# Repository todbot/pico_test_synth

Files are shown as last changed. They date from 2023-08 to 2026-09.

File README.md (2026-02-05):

# pico_test_synth

A simple 
[Raspberry Pi Pico RP2040 or Pico 2 RP2350](https://www.raspberrypi.com/documentation/microcontrollers/raspberry-pi-pico.html)-based
synth to experiment with [`synthio`](https://github.com/todbot/circuitpython-synthio-tricks) and [Mozzi](https://github.com/sensorium/Mozzi).



### pico_test_synth2
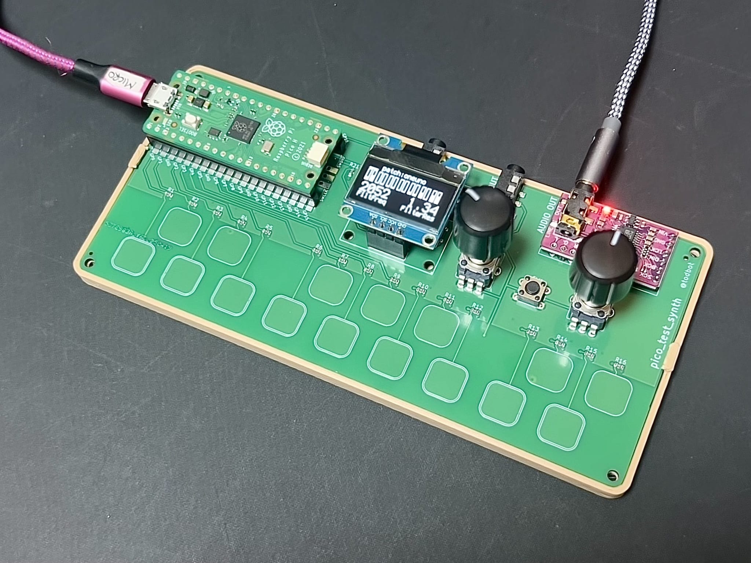
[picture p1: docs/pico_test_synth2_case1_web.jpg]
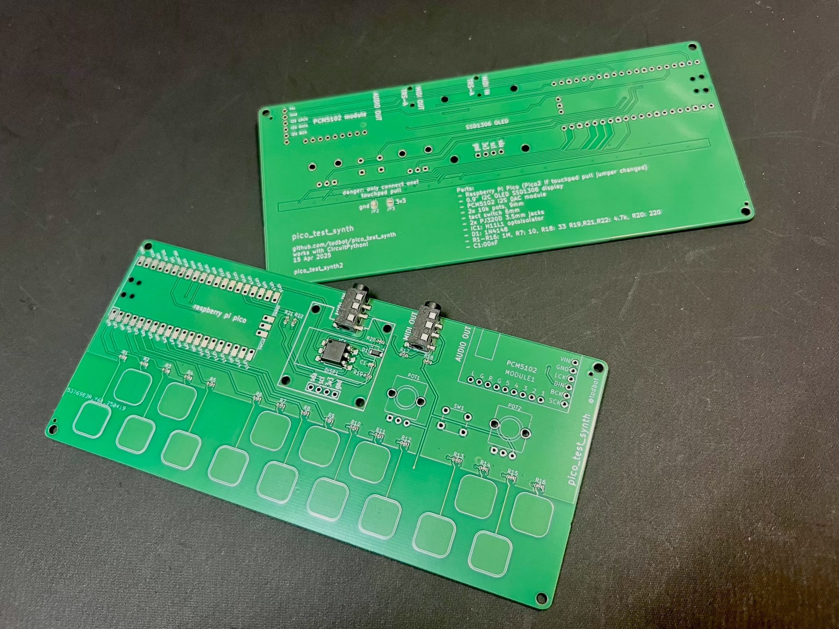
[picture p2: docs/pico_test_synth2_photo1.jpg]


### pico_test_synth, the original
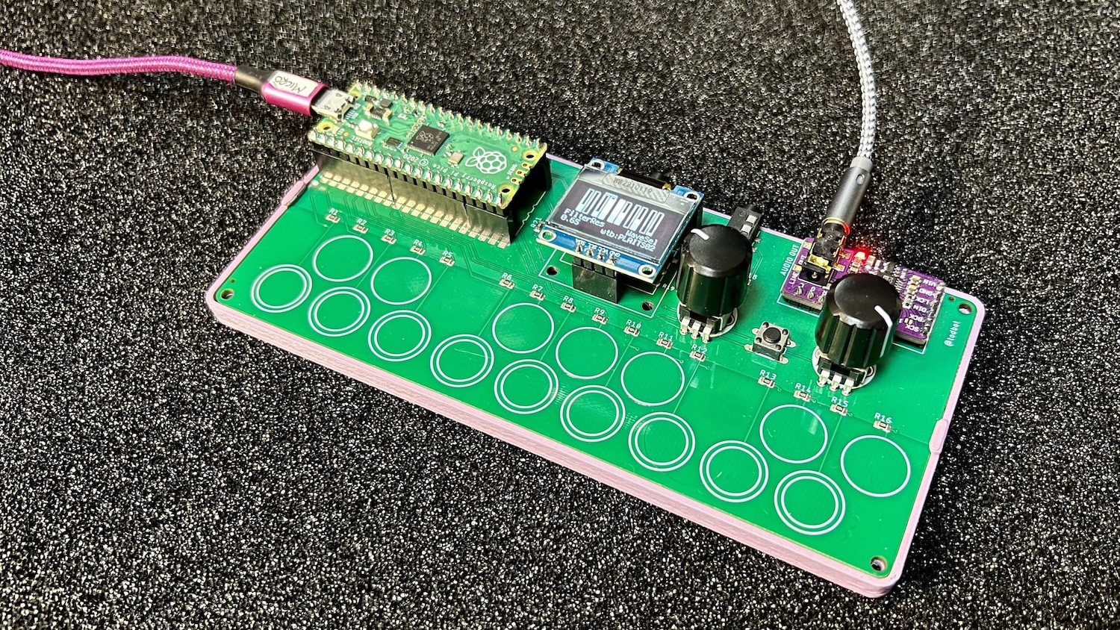
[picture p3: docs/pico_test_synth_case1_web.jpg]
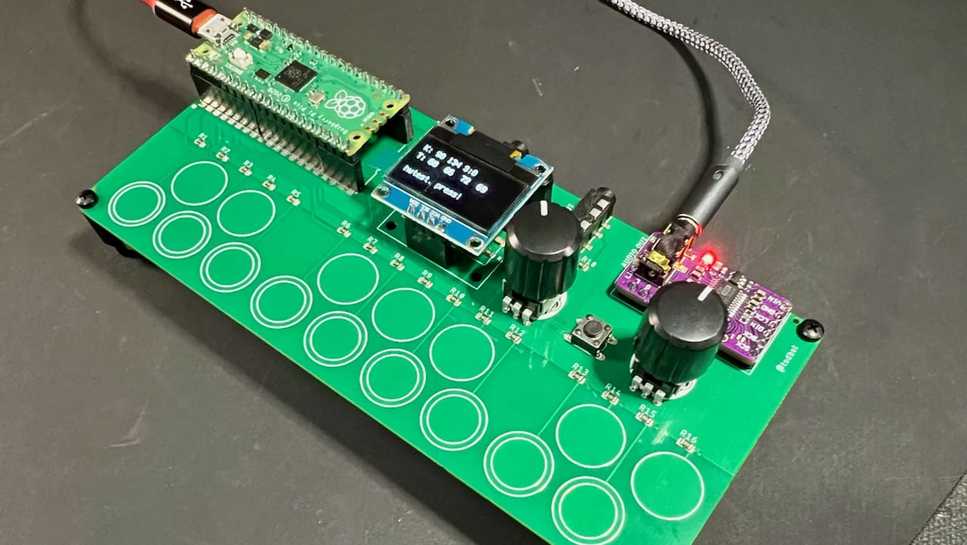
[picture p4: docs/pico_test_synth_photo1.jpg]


<h3>video demo</h3>

video demo (https://www.youtube.com/watch?v=9U2Dn7ckdbs)

** **[Available on Tindie](https://www.tindie.com/products/todbot/pico_test_synth/)** **

### Features

* [PCM5102 I2S DAC](https://todbot.com/blog/2023/05/16/cheap-stereo-line-out-i2s-dac-for-circuitpython-arduino-synths/) footprint for high-quality stereo audio out
* Optoisolated MIDI Input via [MIDI TRS-A 3.5mm jack](https://www.perfectcircuit.com/make-noise-0-coast-midi-cable.html)
* MIDI output via MIDI TRS-A 3.5mm jack
* Two pots for controlling parameters
* One switch for controlling parameters
* 16 capsense touch buttons for synth triggering
* USB MIDI in/out of course too
* **(NOTE: the pico_test_synth1 PCB will NOT work with the Pico2, since its RP2350 chip has a hardware error)**

#### pico_test_synth2 vs pico_test_synth

- Both use the same components
- Both run the same code 
- Both fit in the same enclosure
- `pico_test_synth2` drawn in Kicad; `pico_test_synth` drawn in Eagle
- `pico_test_synth2` has square buttons; `pico_test_synth` has round buttons
- `pico_test_synth2` can work with Pico 2 and Pico 
- `pico_test_synth` can only work with Pico1

### Software

Programs written for [`qtpy_synth`](https://github.com/todbot/qtpy_synth/)
will work with this board too with minimal changes.

Some programs written specifically for this board:

* [TBish](https://github.com/todbot/pico_test_synth/tree/main/circuitpython/tbish/) - a TB303-like synth demo ([video demo](https://www.youtube.com/watch?v=1AflpXbEIno))
* [monosynth1](https://github.com/todbot/pico_test_synth/tree/main/arduino/monosynth1) - a full Moog-like monosynth written in Arduino & Mozzi 
* [hwtest](https://github.com/todbot/pico_test_synth/tree/main/circuitpython/hwtest/code.py) - test out the hardware with a simple synth ([video demo](https://www.youtube.com/watch?v=9U2Dn7ckdbs))
* [wavesynth](https://github.com/todbot/pico_test_synth/tree/main/circuitpython/wavesynth/) - port of wavesynth for qtpy_synth board with some improvements

#### See also:
- [CircuitPython Synthio Tricks](https://github.com/todbot/circuitpython-synthio-tricks)
  - Contains [many other synthio examples](https://github.com/todbot/circuitpython-synthio-tricks/tree/main/examples) that can work with this synth with minimal changes
- [Synthio Tutorial](https://todbot.github.io/CircuitPython_Synthio_Tutorial/) 
  - a getting-started guide for `synthio` ending with some full synthesiser voices 

### Enclosure

As seen in the photos, there is a simple [3d-printable enclosure available on Printables](https://www.printables.com/model/784414-case-for-pico_test_synth-circuitpython-synthesizer). 
It's fast to print and you can snap the PCB in to quickly get started,
or use M2.5 screws and nuts to secure the PCB more permanently.

### Pins used

The board uses all of the Raspberry Pi Pico pins:

* `board.GP28` - middle button
* `board.GP27` - right knob
* `board.GP26` - left knob
* `board.GP22` - I2S data
* `board.GP21` - I2S LR  clock
* `board.GP20` - I2S bit clock
* `board.GP19` - I2C SCL for OLED display
* `board.GP18` - I2C SDA for OLED display
* `board.GP17` - TRS UART MIDI in
* `board.GP16` - TRS UART MIDI out
* `board.GP15`..`board.GP0` -- touch pads 1-16

For more details see [`hwtest/code.py`](https://github.com/todbot/pico_test_synth/tree/main/circuitpython/hwtest/code.py).

### Schematics

#### pico_test_synth2 ####
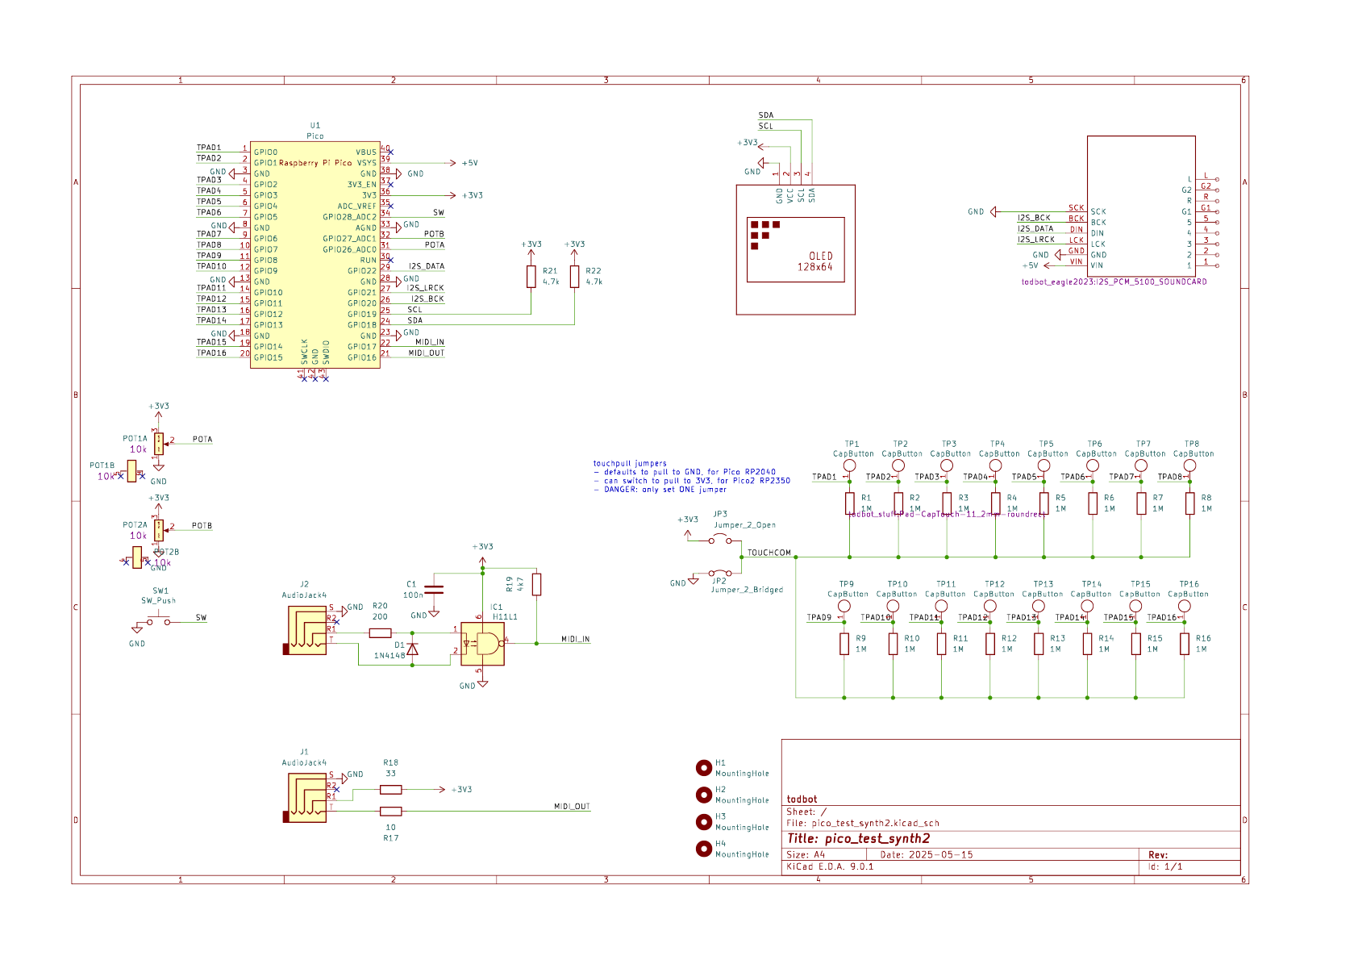
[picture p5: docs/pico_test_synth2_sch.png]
[](./schematics/pico_test_synth2/pico_test_synth2_sch.pdf)

#### pico_test_synth, original ####
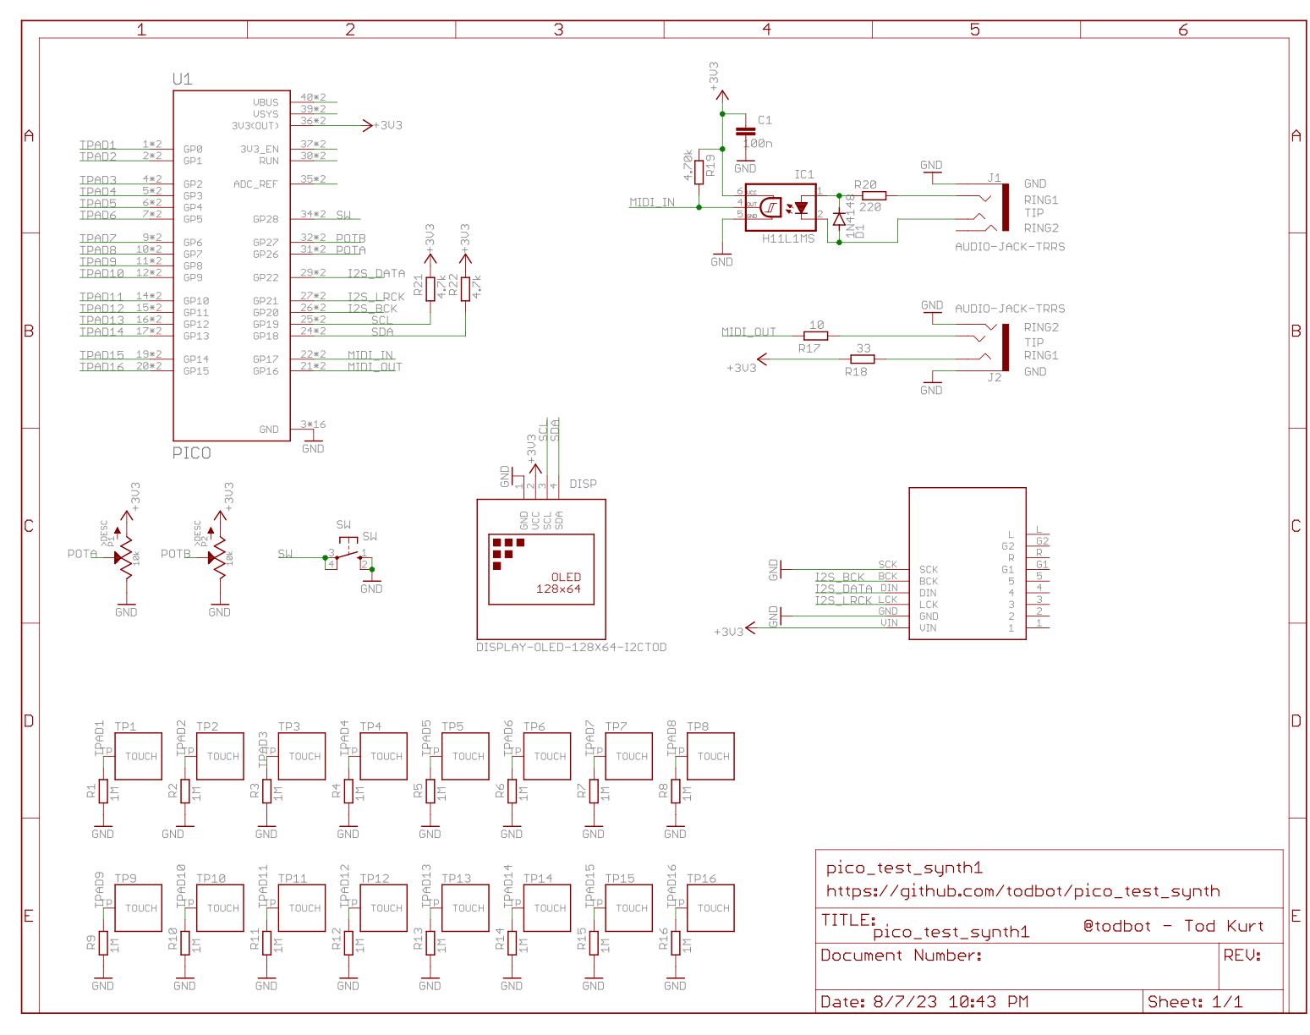
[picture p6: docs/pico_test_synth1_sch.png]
[](./schematics/pico_test_synth1/pico_test_synth1_sch.pdf)

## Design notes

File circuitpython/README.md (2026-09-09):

# CircuitPython apps for pico_test_synth

CircuitPython demos for the pico_test_synth and pico_test_synth2 boards.

* [`hwtest`](hwtest/) - canonical hardware/pin reference for this board and a simple synth. Start here. 
* [`synthtools_polysynth`](synthtools_polysynth/) - 16-pad chromatic polysynth based on `SubtractiveSynth`, 18 parameters grouped into 6 named sections, two pots per pair
* [`synthtools_swarm`](synthtools_swarm/) - `SwarmSynth` drone — up to 8 detuned oscillators per note 
* [`synthtools_arp`](synthtools_arp/) - hold pads, `Arpeggiator` plays them back 
* [`wavesynth`](wavesynth/) - wavetable polysynth with 9 saveable patches 
* [`tbish`](tbish/) - TB-303-like monosynth with step-sequencer
* [`tbish2`](tbish2/) - TB-303-style acid bassline on `BasslineSynth`, with a step sequencer. Will try to use `audiofilters`/`audiodelays` for fatter sound
* [`synth1`](synth1/) - small demo synth: filter sweeps, detune, MIDI in 

## Install

You can use circup to install needed libraries:
```
circup install -r requirements.txt
```

For each demo, copy the contents of the directory flat onto the CIRCUITPY
root and reset.

## Notes

### Sample rate

These demos run at 22050 Hz sample rate in stereo, this works on RP2040 (Pico)
and RP2350 (Pico2). The Pico2 can do 44100 Hz sample rate. 

Every demo sets `FILT_F_MAX` on its synth subclass before constructing it to
be below the Nyquist frequency for the sample rate (e.g. 11 kHz for 22050 Hz),
since filter frequency above Nyquist is undefined.

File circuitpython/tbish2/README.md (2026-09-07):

# TBish2 synth

A TB-303 inspired monophonic bass synth: [`tbish/`](../tbish/) rebuilt on
[`synthtools`](https://github.com/todbot/CircuitPython_SynthTools)'
`BasslineSynth`.

Video demo of the original: https://www.youtube.com/watch?v=1AflpXbEIno

## Why this exists

`BasslineSynth` is a direct port of `tbish/tbish_synth.py` into the
library, and along the way it finished the four `# FIXME` items still
sitting in that file's `note_on_step()`. So `tbish2` is the same
instrument with:

- **accent → resonance** (`accent_q`) and **accent → cutoff**
  (`accent_cutoff`), not just accent → level
- **a real `slide_time`** instead of a hardcoded 0.1 s
- keyboard tracking, and the accent applied without contaminating the
  patch (it writes spare block inputs, so `filt_f`/`filt_q` still read
  back clean)

Four of tbish's eight files are gone into the library:

| `tbish/` | here |
|---|---|
| `tbish_synth.py` | `synthtools.BasslineSynth` |
| `tbish_sequencer.py` | `synthtools.step_sequencer.StepSequencer` |
| `paramset.py` | `synthtools.paramset` |
| `pitch_glider.py` | dropped; slide is `Synth.mono` + `glide_time` |
| `synth_setup_pts.py` | `pico_test_synth.Hardware`, shared |

`tbish/` is left exactly as it was.

## Controls

- **tap the button** — next pair of parameters (9 pages)
- **hold the button** — play / pause, and save the knobs to `/tbish2.json`
- **touch a pad** — transpose the sequence, −7..+8 semitones

The pots use `ParamSet`'s PICKUP mode: after a page change a pot does
nothing until it passes the value the parameter already has, so the sound
never jumps when you turn one.

## Install

Copy `code.py`, `tbish_ui.py` and `boot.py` to the CIRCUITPY root, then
install the libraries from `circuitpython/`:

```
circup install -r requirements.txt
```

That covers the local `lib/pico_test_synth` board package too; circup
installs from a path as readily as from the bundle.

`boot.py` is what makes the filesystem writable from the board's side.
Without it, saving the knobs on pause fails and the demo prints a note
saying so: everything else works fine.

```
circup install synthtools adafruit_display_text \
               adafruit_displayio_ssd1306 adafruit_debouncer
```

Needs a build with `audiofilters` and `audiodelays` for the 24 dB filter,
drive and delay. Without them it still runs on the voice's own 12 dB
Biquad and says so at boot. Distortion is enabled on RP2350 only:
`tbish/tbish_synth.py` found it too expensive for an RP2040.

## Two parameters changed units from `tbish`

Not renames, if you carry numbers over by hand, convert them:

- **`decay`** was a 0–1 fraction of the step time; it is now **seconds**,
  and it drives the *filter* fall only. The amp's decay is its own knob
  (`ampdec`) and wants to stay *longer*, or the note fades out at the same
  rate the cutoff falls and the sweep is masked.
- **`dtime`** was 0–1 seconds; `fx_delay_ms` is **milliseconds** (max
  1000).

## Notes

Same 303 research links as the original: see [`../tbish/README.md`](../tbish/README.md).

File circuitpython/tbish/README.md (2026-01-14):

# TBish synth

A TB-303 inspired monophonic bass synth.

Video demo: https://www.youtube.com/watch?v=1AflpXbEIno

Current code in here is a technology demo. 
There's no way to edit patterns or play it via MIDI. 

notes: 

- https://www.timstinchcombe.co.uk/index.php?pge=diode
- https://www.firstpr.com.au/rwi/dfish/303-mods/
- https://www.firstpr.com.au/rwi/dfish/303-unique.html
- https://www.kvraudio.com/forum/viewtopic.php?t=346155
- https://modwiggler.com/forum/viewtopic.php?t=289244
- https://github.com/RobinSchmidt/Open303/blob/main/Source/DSPCode/rosic_TeeBeeFilter.h
- https://www.ladyada.net/wiki/x0x/voltagecontrolledfilter
- https://beatproduction.net/how-to-emulate-a-tb-303-with-abletons-operator/
- https://www.reddit.com/r/modular/comments/bvoqff/making_a_eurorack_tb303/

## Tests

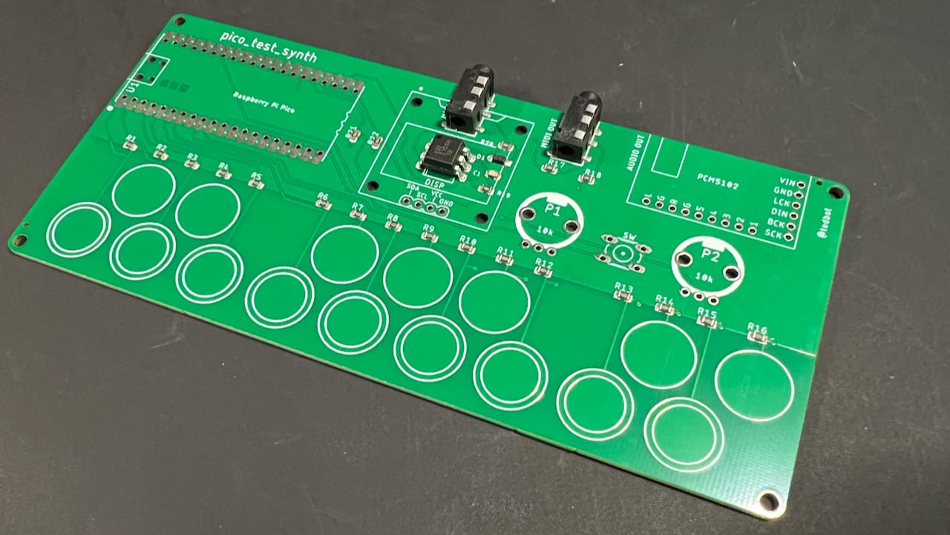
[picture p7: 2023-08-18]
docs/pico_test_synth_photo2.jpg

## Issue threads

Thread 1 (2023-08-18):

Error in readme

riban-bw, 2023-08-18:
The readme says, `board.GP18 - TRS UART MIDI out` but the schematic about this as GP16.

todbot, 2023-08-18:
Thanks! I was scrambling to get this up last night.

Closed 2023-08-18.

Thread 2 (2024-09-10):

You might review the PCM5102 Supply Voltage Requirement

jake653, 2024-09-10:
(I mentioned elsewhere)  The board has 2 - 3.3V regulators, providing better noise isolation for audio section.  Sourcing the board with 3.3V will provide somewhat insufficient voltage and less noise reduction.
 The MicrOne brand ME6211 voltage regulator specs mentions the LDO regulator has a 100mV dropout (@100ma and adequate source voltage) their regulator performance specs are with a 4.3V source.
  The PCM5102 should be more stable with 5V vin., it's logic interfaces are all 3.3V compatible.
  TI specifies their PCM5102 chip operating voltage range is Min 3.0, nom 3.3, max 3.6  Probably worth measuring the onboard regulator outputs in your circuit.

todbot, 2024-10-30:
Thanks. I think you're right.  Before I do another run of these boards, I'll test and make changes.

Closed 2025-02-15.

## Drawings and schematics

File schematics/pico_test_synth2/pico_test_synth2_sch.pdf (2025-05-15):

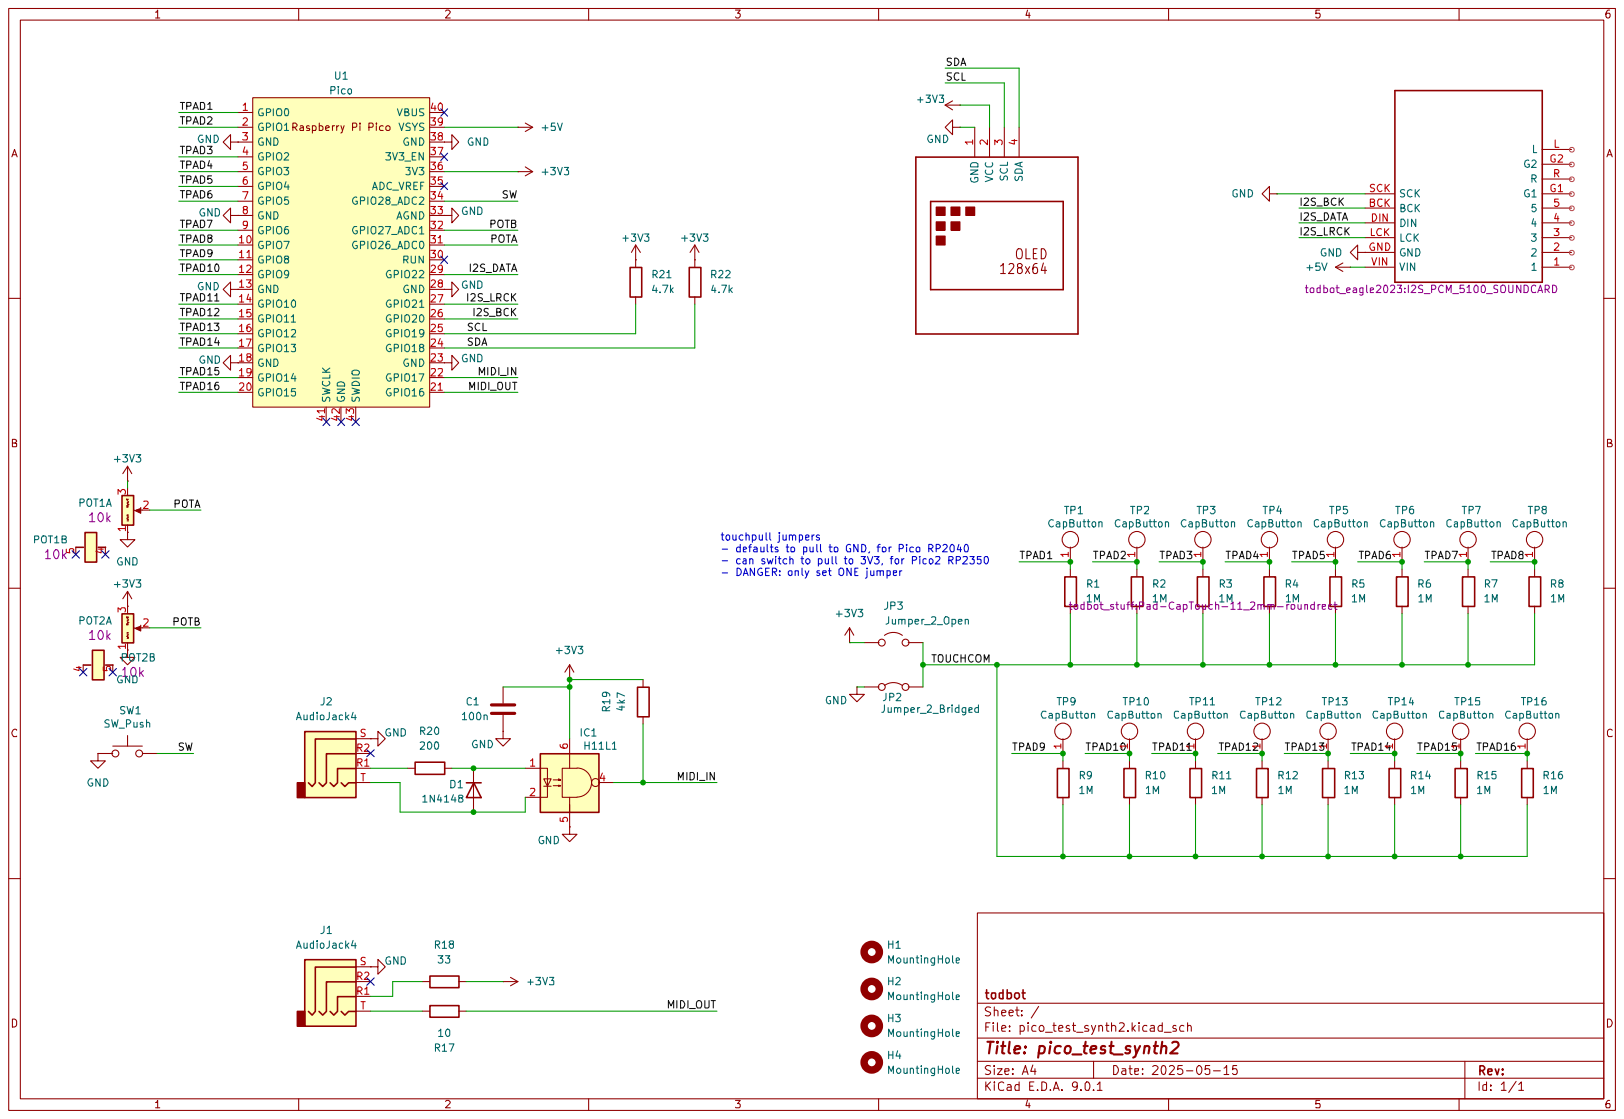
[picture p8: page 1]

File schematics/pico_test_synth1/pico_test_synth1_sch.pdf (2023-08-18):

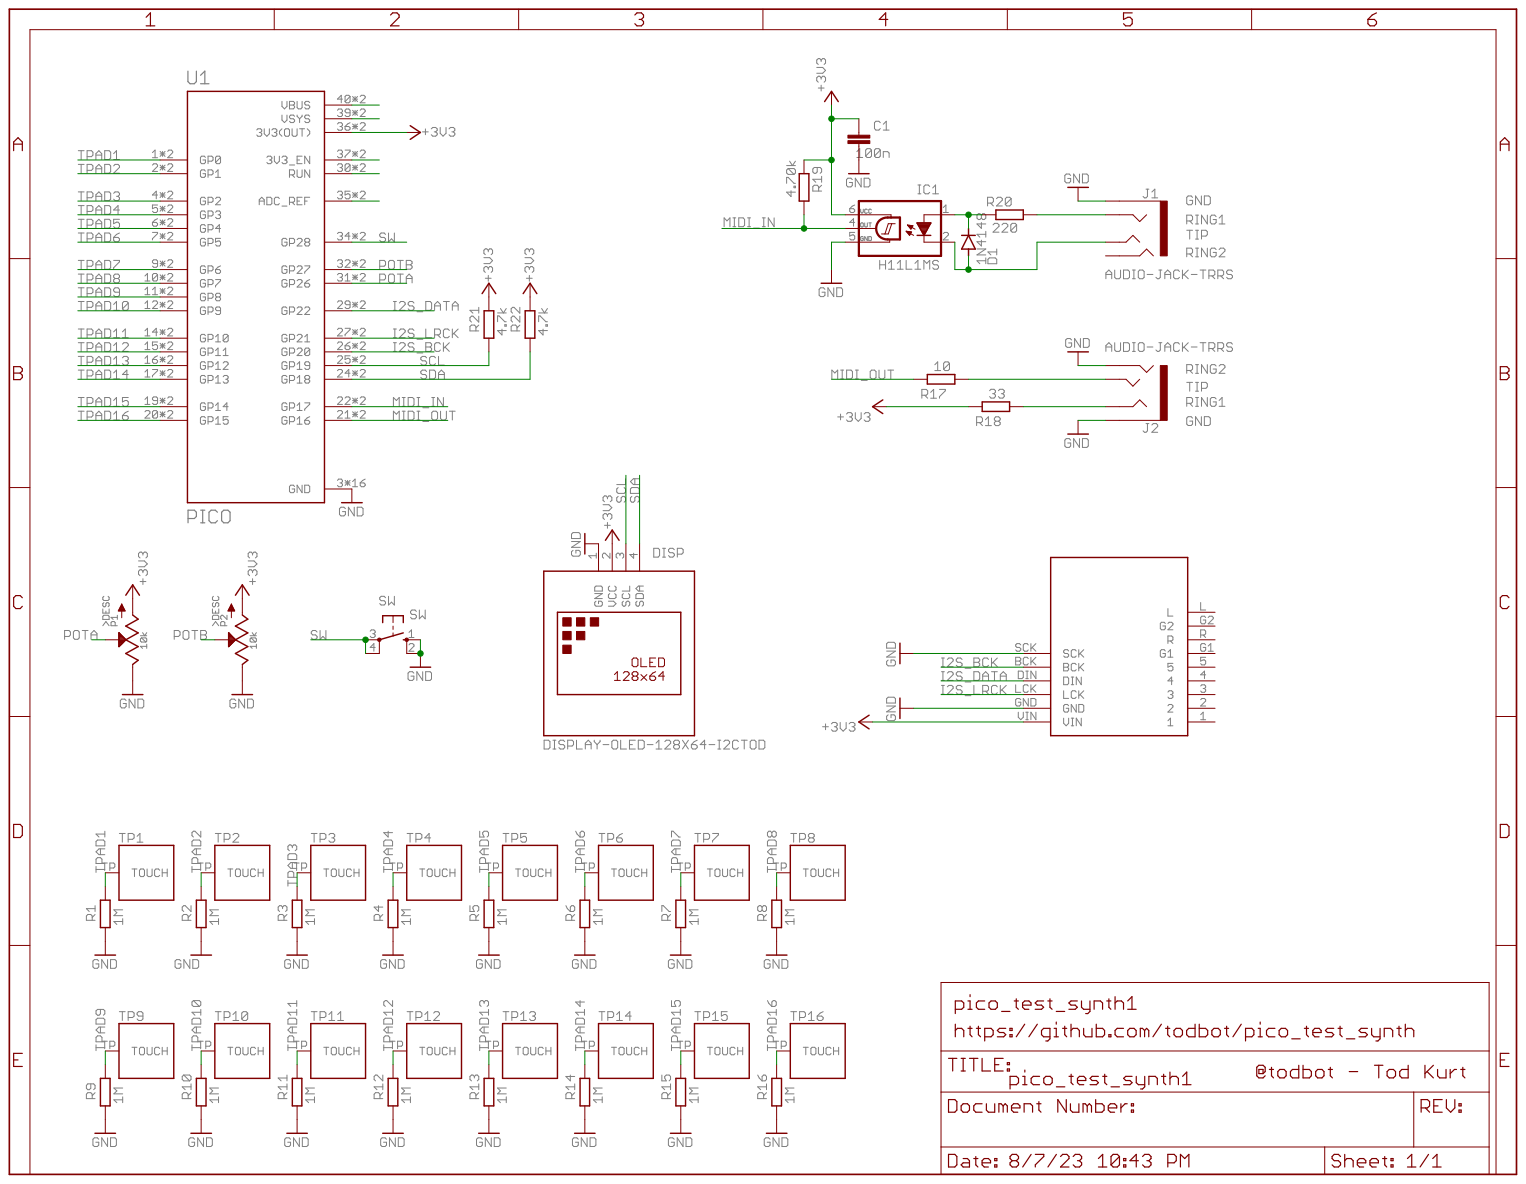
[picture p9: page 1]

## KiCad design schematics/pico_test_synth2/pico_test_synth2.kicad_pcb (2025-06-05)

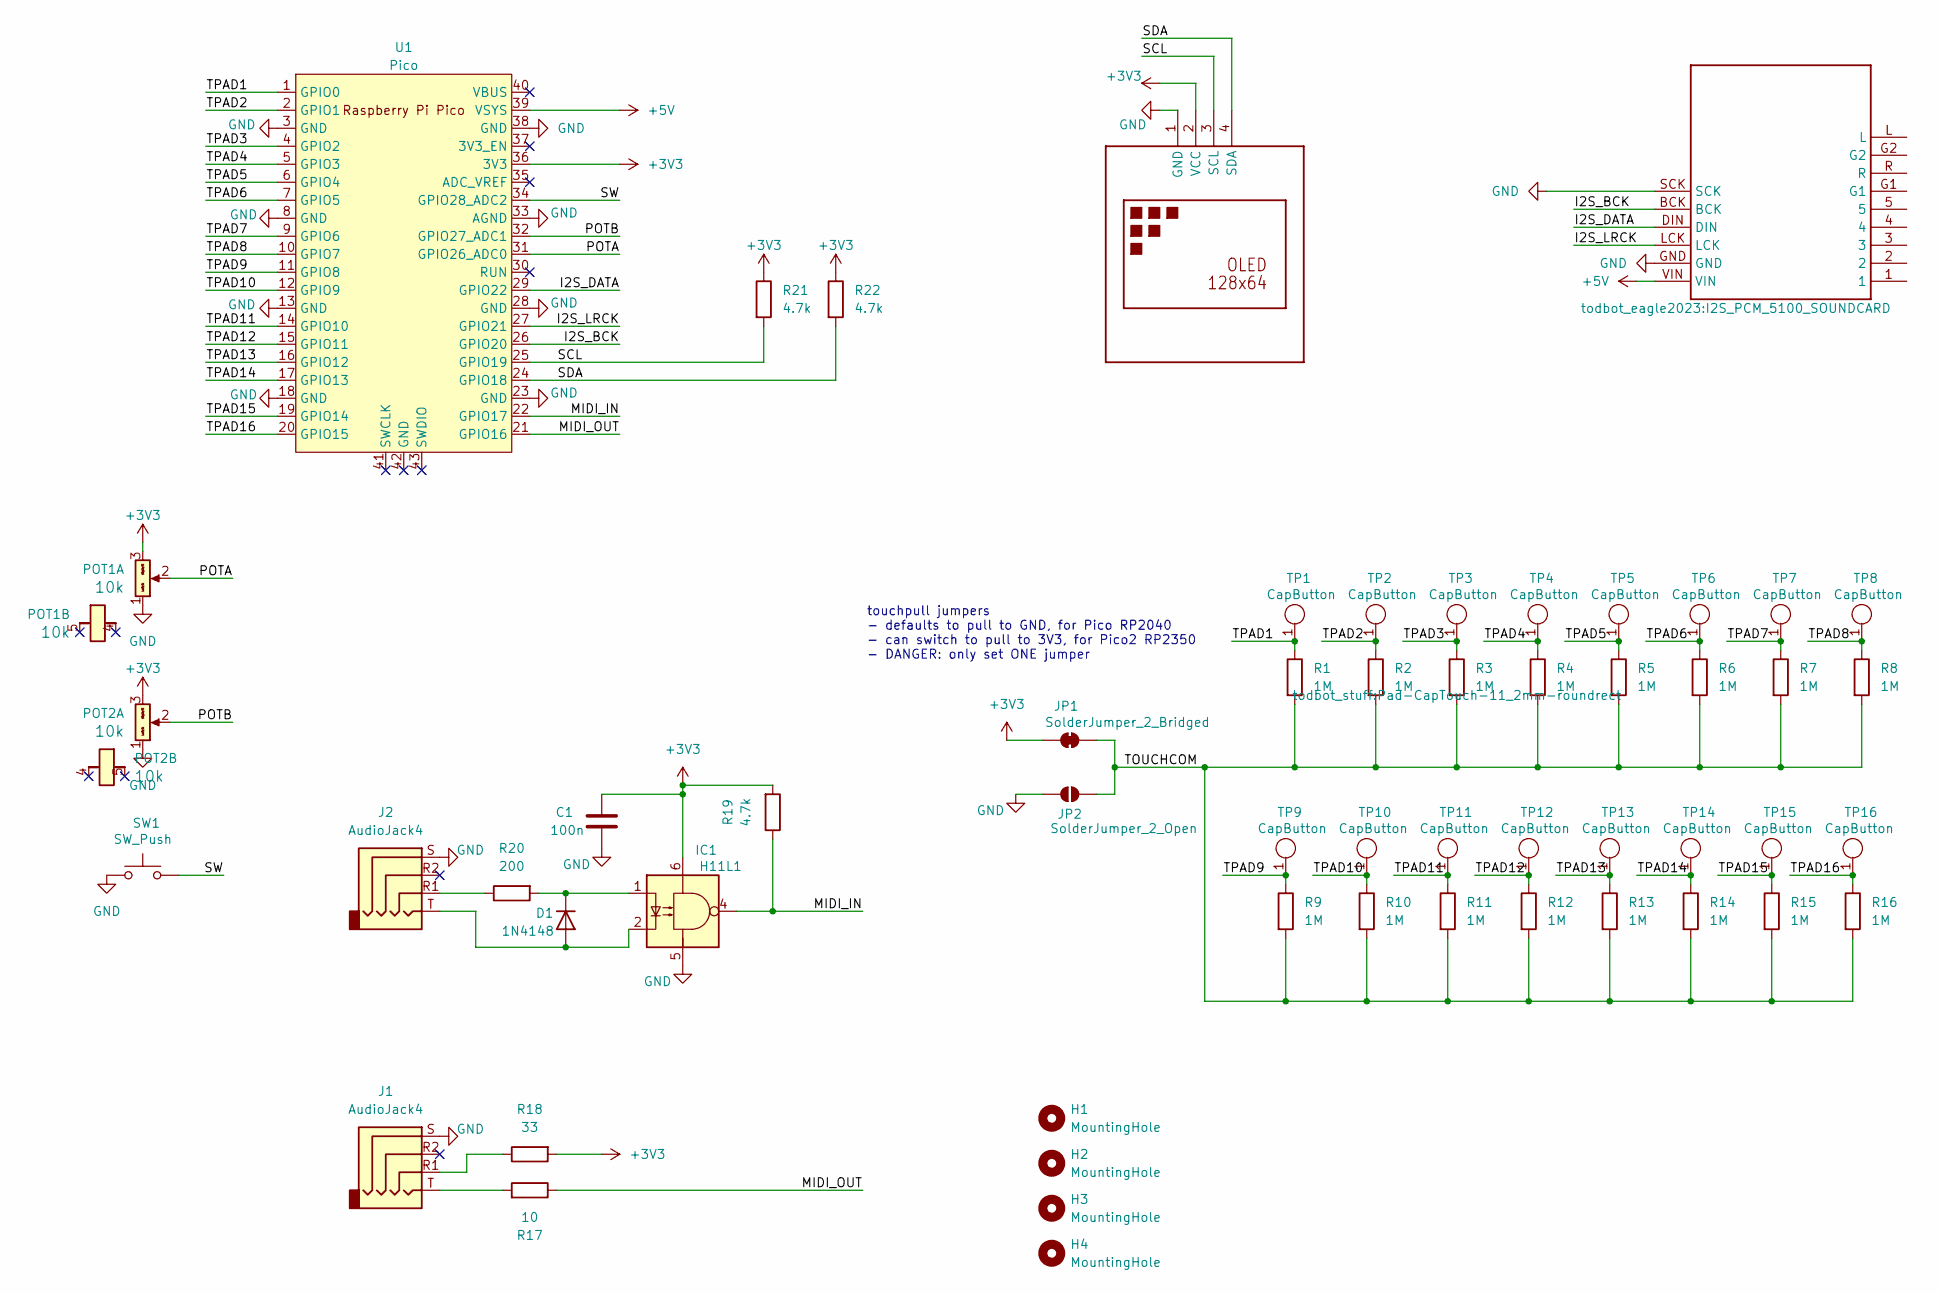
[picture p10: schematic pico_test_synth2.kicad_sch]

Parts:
C1: 100n; C_0603_1608Metric
D1: 1N4148; D_SOD-123
DISP1: OLED-TH_over_L27.8-W27.2-P2.54_C9900033791
H1, H2, H3, H4: MountingHole; MountingHole_2.7mm_M2.5
IC1: H11L1; SMD-6_L7.3-W6.5-P2.54-LS10.2-BL; LCSC C78589
J1, J2: AudioJack4; Jack_3.5mm_PJ320D_Horizontal; LCSC C431535
JP1: SolderJumper_2_Bridged; SolderJumper-2_P1.3mm_Bridged_RoundedPad1.0x1.5mm
JP2: SolderJumper_2_Open; SolderJumper-2_P1.3mm_Open_RoundedPad1.0x1.5mm
MODULE1: I2S_PCM_5100_SOUNDCARD
POT1, POT2: 9mm_NoDet_10k_DShaft; Pot_9mm_DShaft; Part Number RV09BCF-40-25F-B10K-007
R1, R2, R3, R4, R5, R6, R7, R8, R9, R10, R11, R12, R13, R14, R15, R16: 1M; R_0603_1608Metric
R17: 10; R_0603_1608Metric
R18: 33; R_0603_1608Metric
R19, R21, R22: 4.7k; R_0603_1608Metric
R20: 200; R_0603_1608Metric
SW1: SW_Push; SW_PUSH_6mm_H4.3mm
TP1, TP2, TP3, TP4, TP5, TP6, TP7, TP8, TP9, TP10, TP11, TP12, TP13, TP14, TP15, TP16: CapButton; Pad-CapTouch-11_2mm-roundrect
U1: Pico; RPi_Pico_SMD_TH

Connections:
+3V3: C1.1, DISP1.2 (VCC), IC1.6, JP1.1 (A), POT1.3 (Right), POT2.3 (Right), R18.2, R19.2, R21.1, R22.1, U1.36 (3V3)
+5V: MODULE1.VIN, U1.39 (VSYS)
/I2S_BCK: MODULE1.BCK, U1.26 (GPIO20)
/I2S_DATA: MODULE1.DIN, U1.29 (GPIO22)
/I2S_LRCK: MODULE1.LCK, U1.27 (GPIO21)
/MIDI_IN: IC1.4, R19.1, U1.22 (GPIO17)
/MIDI_OUT: R17.1, U1.21 (GPIO16)
/POTA: POT1.2 (Center), U1.31 (GPIO26_ADC0)
/POTB: POT2.2 (Center), U1.32 (GPIO27_ADC1)
/SCL: DISP1.3 (SCL), R21.2, U1.25 (GPIO19)
/SDA: DISP1.4 (SDA), R22.2, U1.24 (GPIO18)
/SW: SW1.1, U1.34 (GPIO28_ADC2)
/TOUCHCOM: JP1.2 (B), JP2.2 (B), R1.2, R2.2, R3.2, R4.2, R5.2, R6.2, R7.2, R8.2, R9.2, R10.2, R11.2, R12.2, R13.2, R14.2, R15.2, R16.2
/TPAD1: R1.1, TP1.1 (A), U1.1 (GPIO0)
/TPAD2: R2.1, TP2.1 (A), U1.2 (GPIO1)
/TPAD3: R3.1, TP3.1 (A), U1.4 (GPIO2)
/TPAD4: R4.1, TP4.1 (A), U1.5 (GPIO3)
/TPAD5: R5.1, TP5.1 (A), U1.6 (GPIO4)
/TPAD6: R6.1, TP6.1 (A), U1.7 (GPIO5)
/TPAD7: R7.1, TP7.1 (A), U1.9 (GPIO6)
/TPAD8: R8.1, TP8.1 (A), U1.10 (GPIO7)
/TPAD9: R9.1, TP9.1 (A), U1.11 (GPIO8)
/TPAD10: R10.1, TP10.1 (A), U1.12 (GPIO9)
/TPAD11: R11.1, TP11.1 (A), U1.14 (GPIO10)
/TPAD12: R12.1, TP12.1 (A), U1.15 (GPIO11)
/TPAD13: R13.1, TP13.1 (A), U1.16 (GPIO12)
/TPAD14: R14.1, TP14.1 (A), U1.17 (GPIO13)
/TPAD15: R15.1, TP15.1 (A), U1.19 (GPIO14)
/TPAD16: R16.1, TP16.1 (A), U1.20 (GPIO15)
GND: C1.2, DISP1.1 (GND), IC1.5, J1.S, J2.S, JP2.1 (A), MODULE1.GND, MODULE1.SCK, POT1.1 (Left), POT2.1 (Left), SW1.2, U1.3 (GND), U1.8 (GND), U1.13 (GND), U1.18 (GND), U1.23 (GND), U1.28 (GND), U1.33 (AGND), U1.38 (GND)
unnamed: D1.2 (A), IC1.2, J2.T
unnamed: D1.1 (K), IC1.1, R20.2
unnamed: J1.R1, R18.1
unnamed: J1.T, R17.2
unnamed: J2.R1, R20.1

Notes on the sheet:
touchpull jumpers - defaults to pull to GND, for Pico RP2040 - can switch to pull to 3V3, for Pico2 RP2350 - DANGER: only set ONE jumper

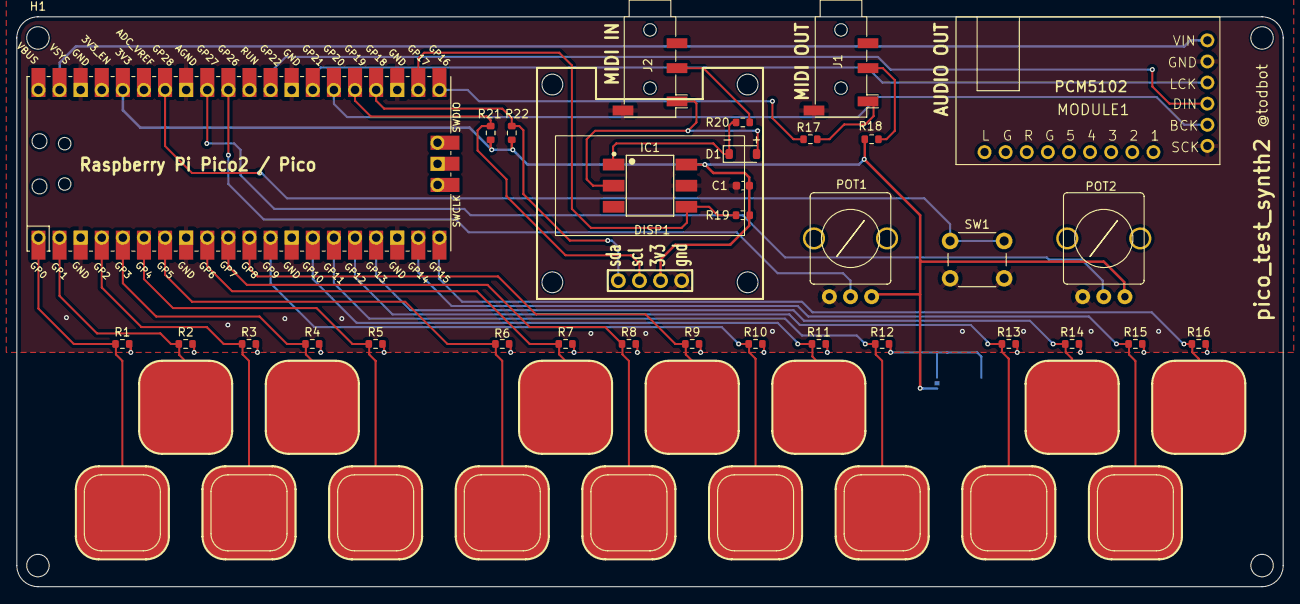
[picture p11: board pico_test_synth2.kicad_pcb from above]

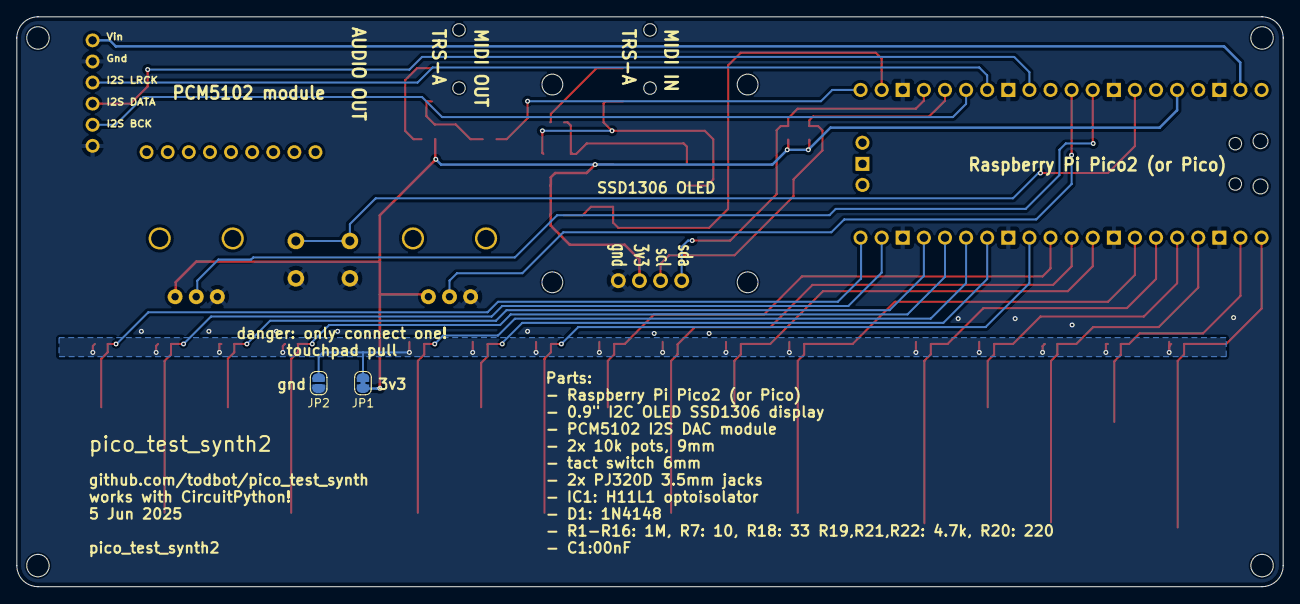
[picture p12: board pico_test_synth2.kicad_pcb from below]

Board: 2 copper layers, 152.4 x 68.6 mm, 55 parts (2 on the bottom side), 35 nets.

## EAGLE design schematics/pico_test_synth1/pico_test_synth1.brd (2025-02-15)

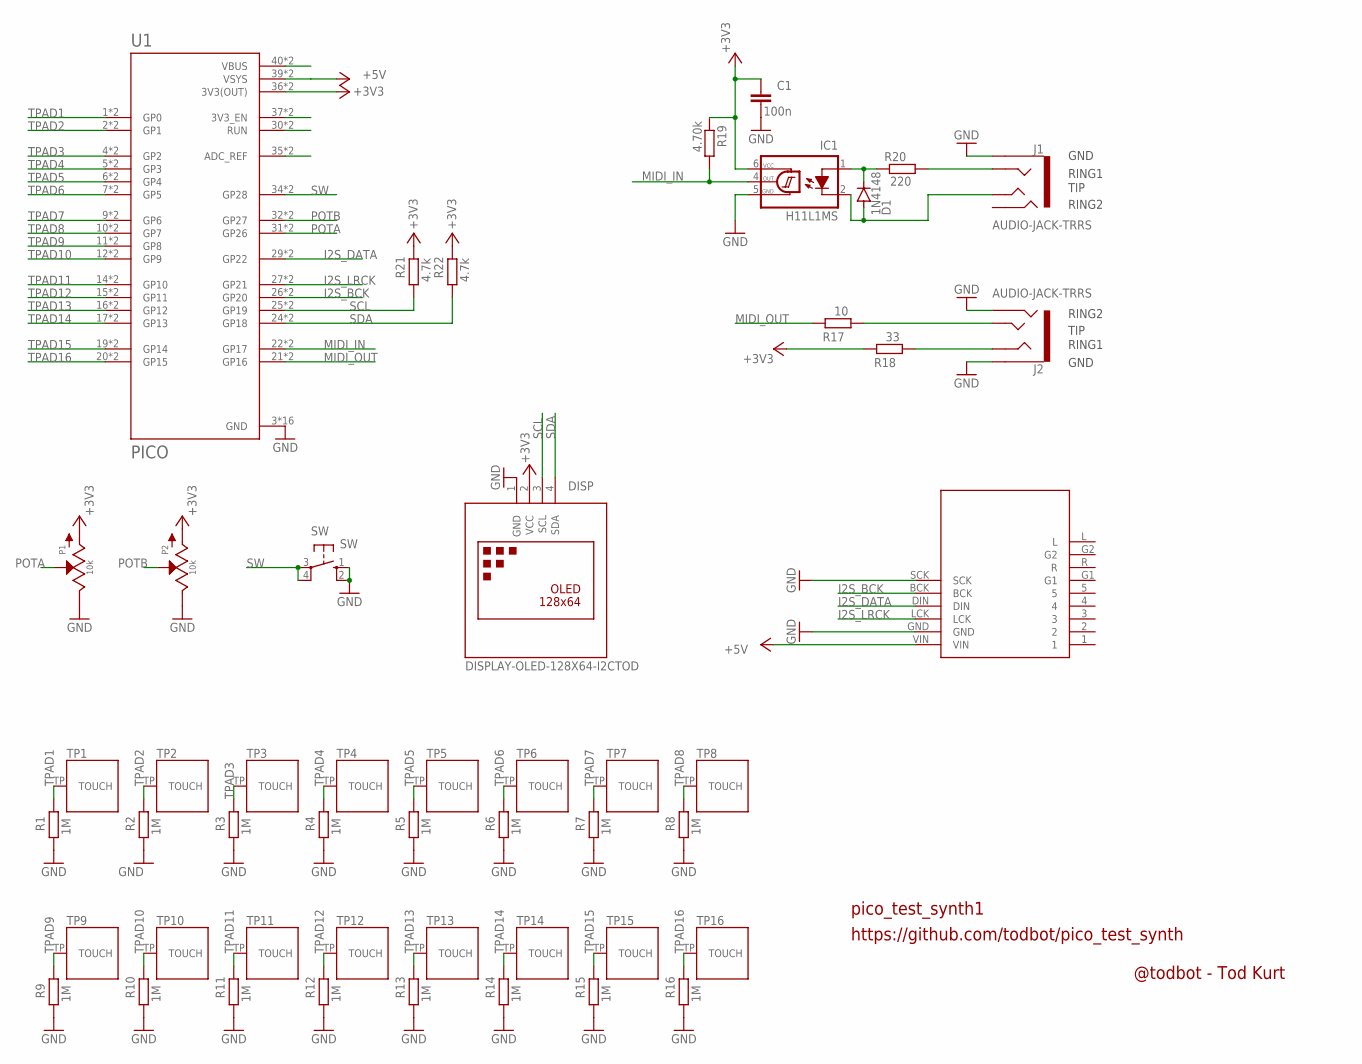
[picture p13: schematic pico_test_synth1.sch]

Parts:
C1: 100n; C0805
D1: 1N4148; SOD123
DISP: DISPLAY-OLED-128X64-I2CTOD; DISPLAY-OLED-128X64-I2C-TOD
IC1: H11L1MS; DIL6-SMD; MPN2 H11L1S; LCSC C78589
J1: AUDIO-JACK-TRRS; PJ-320D_SPARKFUN
J2: AUDIO-JACK-TRRS; PJ-320D_SPARKFUN; LCSC C431535
P1, P2: 10k; OG-POTS_ALPS_POT_VERTICAL_WITHBIGKNOB
R1, R2, R3, R4, R5, R6, R7, R8, R9, R10, R11, R12, R13, R14, R15, R16: 1M; R0805
R17: 10; R0805
R18: 33; R0805
R19: 4.70k; R0805
R20: 220; R0805
R21, R22: 4.7k; R0805
SW: SW; B3F-10XX
TP1, TP2, TP3, TP4, TP5, TP6, TP7, TP8, TP9, TP10, TP11, TP12, TP13, TP14, TP15, TP16: TOUCHPADA; TOUCHPADA_0.5IN
U1: PICO; PICO-PKG-NO_DEBUG
U2: I2S_PCM_51XX_SOUNDCARD; I2S_PCM_5100_SOUNDCARD

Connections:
+3V3: C1.1, DISP.2 (VCC), IC1.6 (VCC), P1.P$3 (A), P2.P$3 (A), R18.1, R19.1, R21.1, R22.1, U1.36 (3V3(OUT)), U1.P$36 (3V3(OUT))
+5V: U1.39 (VSYS), U1.P$39 (VSYS), U2.VIN
GND: C1.2, DISP.1 (GND), IC1.5 (GND), J1.EARTH, J2.EARTH, J2.RING2, P1.P$1 (E), P2.P$1 (E), R1.2, R2.2, R3.2, R4.2, R5.2, R6.2, R7.2, R8.2, R9.2, R10.2, R11.2, R12.2, R13.2, R14.2, R15.2, R16.2, SW.1 (S), SW.2 (S1), U1.3 (GND), U1.8 (GND), U1.13 (GND), U1.18 (GND), U1.23 (GND), U1.28 (GND), U1.33 (GND), U1.38 (GND), U1.P$3 (GND), U1.P$8 (GND), U1.P$13 (GND), U1.P$18 (GND), U1.P$23 (GND), U1.P$28 (GND), U1.P$33 (GND), U1.P$38 (GND), U2.GND, U2.SCK
I2S_BCK: U1.26 (GP20), U1.P$26 (GP20), U2.BCK
I2S_DATA: U1.29 (GP22), U1.P$29 (GP22), U2.DIN
I2S_LRCK: U1.27 (GP21), U1.P$27 (GP21), U2.LCK
MIDI_IN: IC1.4 (OUT), R19.2, U1.22 (GP17), U1.P$22 (GP17)
MIDI_OUT: R17.1, U1.21 (GP16), U1.P$21 (GP16)
unnamed: U1.35 (ADC_REF), U1.P$35 (ADC_REF)
unnamed: J1.RING1, R20.2
unnamed: U1.30 (RUN), U1.P$30 (RUN)
unnamed: U1.37 (3V3_EN), U1.P$37 (3V3_EN)
unnamed: U1.40 (VBUS), U1.P$40 (VBUS)
unnamed: D1.C, IC1.1 (A), R20.1
unnamed: D1.A, IC1.2 (C), J1.TIP
unnamed: J2.RING1, R18.2
unnamed: J2.TIP, R17.2
POTA: P1.P$2 (S), U1.31 (GP26), U1.P$31 (GP26)
POTB: P2.P$2 (S), U1.32 (GP27), U1.P$32 (GP27)
SCL: DISP.3 (SCL), R21.2, U1.25 (GP19), U1.P$25 (GP19)
SDA: DISP.4 (SDA), R22.2, U1.24 (GP18), U1.P$24 (GP18)
SW: SW.3, SW.4 (P1), U1.34 (GP28), U1.P$34 (GP28)
TPAD1: R1.1, TP1.TP, U1.1 (GP0), U1.P$1 (GP0)
TPAD2: R2.1, TP2.TP, U1.2 (GP1), U1.P$2 (GP1)
TPAD3: R3.1, TP3.TP, U1.4 (GP2), U1.P$4 (GP2)
TPAD4: R4.1, TP4.TP, U1.5 (GP3), U1.P$5 (GP3)
TPAD5: R5.1, TP5.TP, U1.6 (GP4), U1.P$6 (GP4)
TPAD6: R6.1, TP6.TP, U1.7 (GP5), U1.P$7 (GP5)
TPAD7: R7.1, TP7.TP, U1.9 (GP6), U1.P$9 (GP6)
TPAD8: R8.1, TP8.TP, U1.10 (GP7), U1.P$10 (GP7)
TPAD9: R9.1, TP9.TP, U1.11 (GP8), U1.P$11 (GP8)
TPAD10: R10.1, TP10.TP, U1.12 (GP9), U1.P$12 (GP9)
TPAD11: R11.1, TP11.TP, U1.14 (GP10), U1.P$14 (GP10)
TPAD12: R12.1, TP12.TP, U1.15 (GP11), U1.P$15 (GP11)
TPAD13: R13.1, TP13.TP, U1.16 (GP12), U1.P$16 (GP12)
TPAD14: R14.1, TP14.TP, U1.17 (GP13), U1.P$17 (GP13)
TPAD15: R15.1, TP15.TP, U1.19 (GP14), U1.P$19 (GP14)
TPAD16: R16.1, TP16.TP, U1.20 (GP15), U1.P$20 (GP15)

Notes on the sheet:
pico_test_synth1
https://github.com/todbot/pico_test_synth
RING2
RING1
GND
TIP
@todbot - Tod Kurt

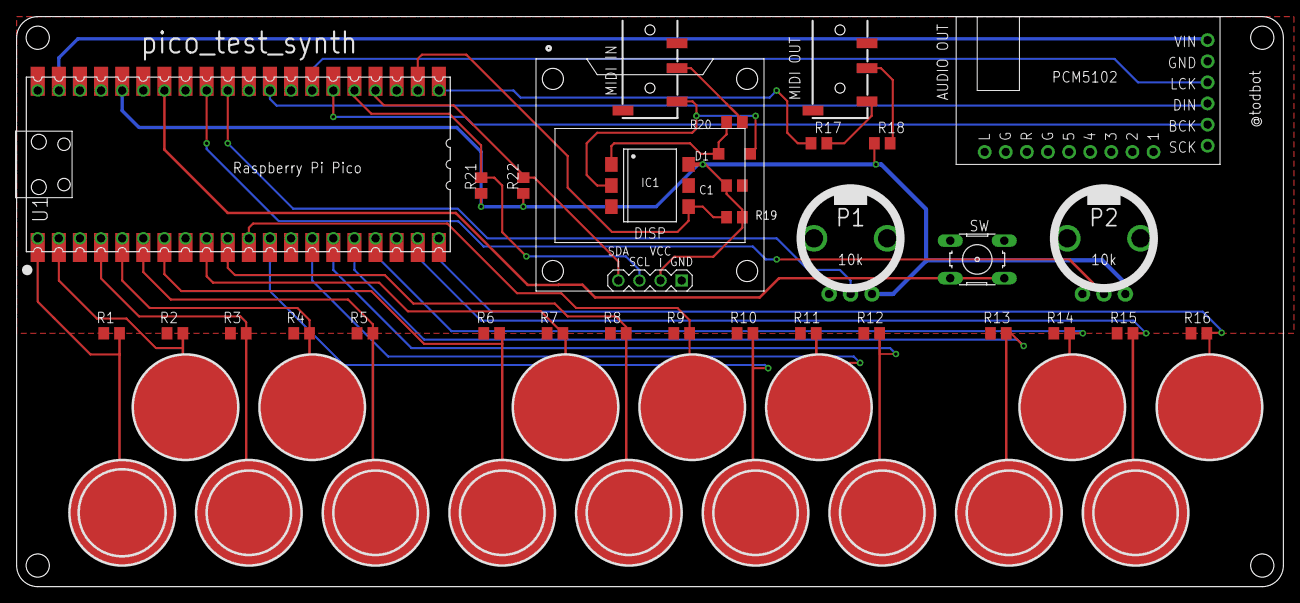
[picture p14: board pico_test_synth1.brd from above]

Board: 2 copper layers, 152.4 x 68.6 mm, 49 parts (0 on the bottom side), 38 nets.

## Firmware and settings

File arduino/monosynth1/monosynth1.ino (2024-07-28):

/**
 * monosynth1 wubwubwub synth using LowPassFilter
 * based on 'monosynth1' from https://github.com/todbot/mozzi_experiments
 * based MozziScout "mozziscout_monosynth1"
 *
 * Responds to Serial (DIN) MIDI In and USB MIDI
 *
 * @todbot 3 Jan 2021
 **/

// set DEBUG_MIDI 1 to show CCs received in Serial Monitor
#define DEBUG_MIDI 1

#include <Adafruit_TinyUSB.h>
#include <MIDI.h>
#include <TouchyTouch.h>
#include <Wire.h>
#include <Bounce2.h>
#include <Adafruit_GFX.h>
#include <Adafruit_SSD1306.h>
#include "fonts/Dialog_plain_10.h"
#include "fonts/Dialog_bold_12.h"
#include "fonts/Dialog_plain_8.h"
#define myfont Dialog_plain_10
#define myfontB Dialog_bold_12
#define myfontSM Dialog_plain_8

#include "SynthUI.h"

#include "MozziConfigValues.h"  // for named option values
#define MOZZI_AUDIO_MODE MOZZI_OUTPUT_I2S_DAC
#define MOZZI_AUDIO_CHANNELS MOZZI_STEREO 
#define MOZZI_AUDIO_BITS 16
#define MOZZI_AUDIO_RATE 32768 // must be power of two
#define MOZZI_I2S_PIN_BCK 20
#define MOZZI_I2S_PIN_WS (MOZZI_I2S_PIN_BCK+1) // HAS TO BE NEXT TO pBCLK, i.e. default is 21
#define MOZZI_I2S_PIN_DATA 22
#define MOZZI_ANALOG_READ MOZZI_ANALOG_READ_NONE  // we're using regular analogRead()
// #define OSCIL_DITHER_PHASE 1 
// Mozzi's controller update rate, seems to have issues at 1024
// If slower than 512 can't get all MIDI from Live
#define MOZZI_CONTROL_RATE 512  // mozzi rate for updateControl()
//#define MOZZI_CONTROL_RATE 128 // mozzi rate for updateControl()

#include <Mozzi.h>
#include <Oscil.h>
#include <tables/triangle_analogue512_int8.h>
#include <tables/square_analogue512_int8.h>
#include <tables/saw_analogue512_int8.h>
#include <tables/cos2048_int8.h> // for filter modulation
#include <ResonantFilter.h>
#include <ADSR.h>
#include <Portamento.h>
#include <mozzi_midi.h> // for mtof()
#include <mozzi_rand.h> // for rand()


const int sw_pin        = 28;
const int knobB_pin     = 27;
const int knobA_pin     = 26;
const int led_pin       = 25;  // regular LED, not neopixel
const int pico_pwr_pin  = 23;  // HIGH = improved ripple (lower noise) but less efficient
const int i2s_data_pin  = 22;  //
const int i2s_lclk_pin  = 21;
const int i2s_bclk_pin  = 20;
const int i2c_scl_pin   = 19;  // on I2C1 aka Wire1
const int i2c_sda_pin   = 18;
const int uart_rx_pin   = 17;  // on UART0 aka Serial1
const int uart_tx_pin   = 16;

// DISPLAY PARAMTERS
const int oled_i2c_addr = 0x3C;
const int dw = 128;
const int dh = 64;

Adafruit_USBD_MIDI usb_midi;                                  // USB MIDI object
MIDI_CREATE_INSTANCE(Adafruit_USBD_MIDI, usb_midi, MIDIusb);  // USB MIDI
MIDI_CREATE_INSTANCE(HardwareSerial, Serial1, MIDIuart);      // Serial MIDI

const int touch_pins[] = { 0, 1, 2, 3, 4, 5, 6, 7, 8, 9, 10, 11, 12, 13, 14, 15 };
const int touch_count = sizeof(touch_pins) / sizeof(int);
const int touch_threshold_adjust = 100;

TouchyTouch touches[touch_count];
Bounce2::Button button;
Adafruit_SSD1306 display(dw, dh, &Wire1, -1);
SynthUI synthui(&display);

// GUI LAYOUT PARAMETERS
int num_disp_params = 3;
int hilite_param = 0;
int line_spacing = 12;  // depends on font
int param_offset = 0;

// SETTINGS
//int portamento_time = 50;  // milliseconds
//int env_release_time = 1000; // milliseconds
byte patch_num = 0; // patch number / program change
bool retrig_lfo = true;

enum KnownCCs {
  Modulation=0,
  Resonance,
  FilterCutoff,
  PortamentoTime,
  EnvReleaseTime,
  CC_COUNT
};

// mapping of KnownCCs to MIDI CC numbers (this is somewhat standardized)
uint8_t midi_ccs[] = {
  1,   // modulation
  71,  // resonance
  74,  // filter cutoff
  5,   // portamento time
  72,  // env release time
};
uint8_t mod_vals[ CC_COUNT ];

typedef struct {
    int wave_type; // 0 = saw, 
    int filter_type; // 0 = lpf, 1 = bpf, 2 = hpf
    float detune;
    float filter_f;
    float filter_q;
    float filtermod_freq;
    float attack_time;
    float release_time;
} Patch;

//
Oscil<SAW_ANALOGUE512_NUM_CELLS, MOZZI_AUDIO_RATE> aOsc1(SAW_ANALOGUE512_DATA);
Oscil<SAW_ANALOGUE512_NUM_CELLS, MOZZI_AUDIO_RATE> aOsc2(SAW_ANALOGUE512_DATA);

Oscil<COS2048_NUM_CELLS, MOZZI_CONTROL_RATE> kFilterMod(COS2048_DATA); // filter mod

ADSR <CONTROL_RATE, MOZZI_AUDIO_RATE> envelope;
Portamento <MOZZI_CONTROL_RATE> portamento;
LowPassFilter lpf;

int notes_on = 0;
uint32_t last_debug_millis; 

// core0 is UI
void setup() { 
  Serial1.setRX(uart_rx_pin);
  Serial1.setTX(uart_tx_pin);

  Serial.begin(115200);
  MIDIusb.begin(MIDI_CHANNEL_OMNI);
  MIDIusb.turnThruOff();   // turn off echo
  MIDIuart.begin(MIDI_CHANNEL_OMNI); // don't forget OMNI
  MIDIuart.turnThruOff();  // turn off echo

  // KNOBS & BUTTON & LED
  pinMode(led_pin, OUTPUT);
  button.attach(sw_pin, INPUT_PULLUP);
  button.setPressedState(LOW);

  // TOUCH
  for (int i = 0; i < touch_count; i++) {
    touches[i].begin(touch_pins[i]);
    touches[i].threshold += touch_threshold_adjust;  // make a bit more noise-proof
  }

  // DISPLAY
  Wire1.setSDA(i2c_sda_pin);
  Wire1.setSCL(i2c_scl_pin);
  Wire1.begin();

  if (!display.begin(SSD1306_SWITCHCAPVCC, oled_i2c_addr)) {
    Serial.println(F("SSD1306 allocation failed"));
    for (;;) ;  // Don't proceed, loop forever
  }
  display.setRotation(2);  // rotated 180
  display.clearDisplay();

  int16_t x1, y1;
  uint16_t w, h;
  display.setFont(&myfontB);
  display.getTextBounds("HELLO", 0, 20, &x1, &y1, &w, &h);
  line_spacing = h * 1.5;

  synthui.print_text(0, line_spacing * 1, "PICO_TEST_SYNTH", &myfont);
  display.display();
  delay(500);
  synthui.print_text(15, line_spacing * 2, "MONOSYNTH1");
  //synthui.print_textf(0, line_spacing * 4, "params:%d patches:%d", num_patch_params, num_patches);
  display.display();
  delay(2500);
}

// core0 is UI
void loop() { 
  handleMIDI();
  
  updateInputs();

  if( millis() - last_debug_millis > 100 ) { 
    last_debug_millis = millis();
    Serial.print("boop: ");
    for (int i = 0; i < touch_count; i++) {
      char t = touches[i].touched() ? '|' : ' ';  // indicates a touched value
      int touchval = touches[i].raw_value / 100;  // make a more printalbe value
      Serial.printf("%c%2d%c", t, touchval, t);
    }
    Serial.println();
  }

}

// core1 is audio
void setup1() {

  delay(1000);

  startMozzi(MOZZI_CONTROL_RATE);
  handleProgramChange(patch_num); // set our initial patch
 }
 
// core1 is audio
void loop1() {
  audioHook();
}

//
void handleNoteOn(byte channel, byte note, byte velocity) {
  (void) channel;
  (void) velocity;
  #if DEBUG_MIDI
  Serial.println("midi_test handleNoteOn!");
  #endif
  digitalWrite(LED_BUILTIN,HIGH);
  portamento.start(note);
  envelope.noteOn();
  notes_on++;
}

//
void handleNoteOff(byte channel, byte note, byte velocity) {
  (void) channel;
  (void) note;
  (void) velocity;
  digitalWrite(LED_BUILTIN,LOW);
  notes_on--;
  if( ! notes_on ) { 
    envelope.noteOff();
  }
}

//
void handleControlChange(byte channel, byte cc_num, byte cc_val) {
  (void) channel;
  #if DEBUG_MIDI 
  Serial.printf("CC %d %d\n", cc_num, cc_val);
  #endif
  for( int i=0; i<CC_COUNT; i++) { 
    if( midi_ccs[i] == cc_num ) { // we got one
      mod_vals[i] = cc_val;
      // special cases, not set every updateControl()
      if( i == PortamentoTime ) { 
        portamento.setTime( mod_vals[PortamentoTime] * 2);
      }
      else if( i == EnvReleaseTime ) {
         envelope.setReleaseTime( mod_vals[EnvReleaseTime]*10 );
      }
    }
  }
}

//
void handleProgramChange(byte m) {
  Serial.print("program change:"); Serial.println((byte)m);
  patch_num = m;
  if( patch_num == 0 ) {    
    aOsc1.setTable(SAW_ANALOGUE512_DATA);
    aOsc2.setTable(SAW_ANALOGUE512_DATA);
    
    mod_vals[Modulation] = 0;   // FIXME: modulation unused currently
    mod_vals[Resonance] = 93;
    mod_vals[FilterCutoff] = 50;
    mod_vals[PortamentoTime] = 50; // actually in milliseconds
    mod_vals[EnvReleaseTime] = 100; // in 10x milliseconds (100 = 1000 msecs)

    lpf.setCutoffFreqAndResonance(mod_vals[FilterCutoff], mod_vals[Resonance]*2);
    
    kFilterMod.setFreq(4.0f);  // fast
    envelope.setADLevels(255, 255);
    envelope.setTimes(50, 200, 20000, mod_vals[EnvReleaseTime]*10 );
    portamento.setTime( mod_vals[PortamentoTime] );
  }
  else if ( patch_num == 1 ) {
    aOsc1.setTable(SQUARE_ANALOGUE512_DATA);
    aOsc2.setTable(SQUARE_ANALOGUE512_DATA);
    
    mod_vals[Resonance] = 50;
    mod_vals[EnvReleaseTime] = 15;
    
    lpf.setCutoffFreqAndResonance(mod_vals[FilterCutoff], mod_vals[Resonance]*2);
    
    kFilterMod.setFreq(0.5f);     // slow
    envelope.setADLevels(255, 255);
    envelope.setTimes(50, 100, 20000, (uint16_t)mod_vals[EnvReleaseTime]*10 );
    portamento.setTime( mod_vals[PortamentoTime] );
  }
  else if ( patch_num == 2 ) {
    aOsc1.setTable(TRIANGLE_ANALOGUE512_DATA);
    aOsc2.setTable(TRIANGLE_ANALOGUE512_DATA);
    mod_vals[FilterCutoff] = 65;
    //kFilterMod.setFreq(0.25f);    // slower
    //retrig_lfo = false;
  }
}

//
void handleMIDI() {
  // Serial.printf("handleMIDI: %ld\n", millis());
  while( MIDIusb.read() ) {  // use while() to read all pending MIDI, shouldn't hang
    switch(MIDIusb.getType()) {
      case midi::ProgramChange:
        handleProgramChange(MIDIusb.getData1());
        break;
      case midi::ControlChange:
        handleControlChange(0, MIDIusb.getData1(), MIDIusb.getData2());
        break;
      case midi::NoteOn:
        handleNoteOn( 0, MIDIusb.getData1(),MIDIusb.getData2());
        break;
      case midi::NoteOff:
        handleNoteOff( 0, MIDIusb.getData1(),MIDIusb.getData2());
        break;
      default:
        break;
    }
  }
  while( MIDIuart.read() ) {  // use while() to read all pending MIDI, shouldn't hang
    switch(MIDIuart.getType()) {
      case midi::ProgramChange:
        handleProgramChange(MIDIuart.getData1());
        break;
      case midi::ControlChange:
        handleControlChange(0, MIDIuart.getData1(), MIDIuart.getData2());
        break;
      case midi::NoteOn:
        handleNoteOn( 0, MIDIuart.getData1(),MIDIuart.getData2());
        break;
      case midi::NoteOff:
        handleNoteOff( 0, MIDIuart.getData1(),MIDIuart.getData2());
        break;
      default:
        break;
    }
  }
}

void updateInputs() {
  static int touchi = 0;

  // button.update();
  // knobA_update();
  // knobB_update();

  // only check one touch button per loop since touchytouch spinloops
  touches[touchi].update();
  if( touches[touchi].pressed() ) { 
    handleNoteOn( 0, 36 + touchi, 127);
  }
  if( touches[touchi].released() ) { 
    handleNoteOff( 0, 36 + touchi, 0);
  }
  touchi = (touchi+1) % touch_count;

}

// Mozzi function, called at CONTROL_RATE times per second on core1
void updateControl() {

  lpf.setCutoffFreqAndResonance(mod_vals[FilterCutoff], mod_vals[Resonance]*2);  // don't *2 filter since we want 0-4096Hz

  envelope.update();
  
  Q16n16 pf = portamento.next();  // Q16n16 is a fixed-point fraction in 32-bits (16bits . 16bits)
  aOsc1.setFreq_Q16n16(pf);
  aOsc2.setFreq_Q16n16(pf * 1.001);  // FIXME: adjustable detune plz
}

// Mozzi function, called at AUDIO_RATE times per second on core1
AudioOutput updateAudio() {
  int32_t asig = aOsc1.next() + aOsc2.next();
  asig = lpf.next( asig );
  asig = envelope.next() * asig;
  return StereoOutput::fromAlmostNBit(18, asig, asig); // 16 = 8 signal bits + 8 envelope bits
}

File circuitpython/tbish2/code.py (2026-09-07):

# SPDX-FileCopyrightText: Copyright (c) 2025 Tod Kurt
# SPDX-License-Identifier: MIT
#
# tbish2 -- a TB-303-like acid bassline, on synthtools' BasslineSynth
#
# The tbish/ demo rebuilt on the library. BasslineSynth ports
# tbish/tbish_synth.py with that file's four "FIXME" items done: an accent
# now raises resonance and cutoff as well as level, and a slide has a real
# slide_time.
#
# For a pico_test_synth / pico_test_synth2. Copy code.py, tbish_ui.py
# and boot.py onto the CIRCUITPY root, then, from circuitpython/:
#
#   circup install -r requirements.txt
#
# That pulls synthtools and the local lib/pico_test_synth board package.
# tbish2 draws its own screen (tbish_ui.py), so it never imports
# pico_test_synth.ui.
#
# NEEDS a build with audiofilters and audiodelays for the drive and delay
# knobs and the 24 dB filter. Without them the demo still runs (the
# voice's own 12 dB Biquad only) and says so at boot.
#
#   tap the button   -> next pair of parameters (9 pages)
#   hold the button  -> play / pause (and save the knobs to /tbish2.json)
#   touch a pad      -> transpose the sequence, -7..+8 semitones

import os
import time

import microcontroller
# Do this before any import that allocates. On the original tbish it took
# per-step latency from 10 ms down to 6 ms.
microcontroller.cpu.frequency = 200_000_000

from pico_test_synth import Hardware
from synthtools import BasslineSynth, Patch

# Only the 14 names in synthtools/__init__.py's _LAZY map come from the
# package itself; the rest are module-path imports. Lazy on purpose:
# 23 KB of rp2040 RAM against 52 KB eager.
from synthtools.paramset import Param, ParamSet
from synthtools.step_sequencer import StepSequencer
from tbish_ui import TBishUI

# if we can turn on some extra audio effects
IS_RP2350 = "rp2350" in os.uname()[0]

HOLD_SECS = 0.7  # button press longer than this is a hold, not a tap
UI_INTERVAL = 0.02  # seconds between UI passes
STEPS_PER_BEAT = 4  # 4 = 16th note, 2 = 8th, 1 = quarter
PARAMS_FILE = "/tbish2.json"

# Waveform names, from _builders in synthtools/waves.py. SAW and SQU are
# the 303's own two switch positions; the rest are here because they cost
# nothing. Indexed by a knob, so order is the UI.
WAVES = ("SAW", "SQU", "ASAW", "ASQU", "TRI", "SIN")

# --- the patterns --------------------------------------------------------
# (notes, velocities). A note of 0 is a rest. Velocity is overloaded as the
# per-step flag channel, exactly as in tbish: 1 = slide, 127 = accent.
# StepSequencer steps are [note, vel, gate, on], so this drops straight in.
# fmt: off
SEQS = [
    [[36, 36, 48, 36,  48, 55, 36, 48],
     [127, 80, 80, 80,  127, 1, 30, 1]],

    [[36, 48, 36, 48,  36, 48, 36, 48],
     [127, 80, 1, 1,  127, 1, 30, 1]],

    [[34, 36, 34, 36,  48, 48, 36, 48],
     [127, 80, 120, 80,  127, 11, 127, 80]],

    [[36, 24, 36, 48,  36, 0, 36, 0],
     [127, 1, 1, 80,  127, 80, 127, 80]],
]
# fmt: on
STEP_COUNT = len(SEQS[0][0])
GATE = 0.75  # traditional 303 gate length, as a fraction of a step

# --- the patch -----------------------------------------------------------
# envmod is a FRACTION of filt_f, not Hz, so the sweep tracks the cutoff
# knob: 0.75 of 3000 Hz falls to 750, two octaves.
#
# For that sweep to be heard, `decay` (the FILTER fall) must be SHORTER
# than the gate (94 ms here) and the amp decay LONGER, so the note is
# still loud while the cutoff falls. Equal times just sound like a pluck.
# fmt: off
patch = Patch(
    name="tbish2",
    synth_type="bassline",
    wave="SAW",
    filt_type="LPF",
    filt_f=3000,        # the PEAK the sweep starts from
    filt_q=1.8,         # squelch lives here; push it toward 3-4
    envmod=0.75,
    decay=0.09,         # FILTER fall time, seconds
    amp_env=[0.001, 0.25, 0.0, 0.02],   # sustain 0: every step plucks
    fenv_curve=3,       # fast drop, long tail; reads as "analog"
    accent=0.5,
    accent_cutoff=4000,  # Hz added at full accent
    accent_q=0.8,        # resonance added at full accent
    amp_level=0.75,      # un-accented level, so accents have room
    slide_time=0.09,
    transpose=0,
    fx_filter_stages=1,  # a synthio.Note holds ONE Biquad, so the voice
                         # alone is 12 dB/oct; one extra stage makes 24,
                         # where the squelch really lives
    # STRUCTURAL: these build the effects, so the drive and delay knobs
    # below reach nothing unless they are on here, and nothing can turn
    # them on later.
    fx_distortion_on=IS_RP2350,  # too expensive on an rp2040
    fx_echo_on=True,
    fx_drive=0.0,
    fx_drive_mix=0.0,
    fx_delay_ms=250.0,
    fx_delay_mix=0.0,
    fx_delay_decay=0.3,
)
# fmt: on

hw = Hardware()
BasslineSynth.FILT_F_MAX = hw.sample_rate * 0.45

bass = BasslineSynth(hw.synth, patch)

# Replaces the bare synthesizer Hardware.__init__ played into voice 0 with
# the fx chain's tail; without it the chain is bypassed and the synth just
# sounds thin. Must be redone after any STRUCTURAL fx change.
try:
    hw.mixer.voice[0].play(bass.output)
    print("filter: 24 dB/octave (1 extra stage)")
except ImportError:
    print("no audiofilters in this build; 12 dB/oct, no drive, no delay")
    hw.mixer.voice[0].play(bass.synthio)
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

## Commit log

2023-08-18 fix up pin usage typos, addresses issue #1
    [code.py]
2024-02-16 first cut at port of wavesynth from qtpy_synth
2024-02-17 add octave and volume to synthio_instrument patches, expose those params in wavesynth, misc cleanups and fixes. still hate pickup mode
    [code.py]
2024-02-27 add case link to README
2024-02-28 fix more new wavesynth bugs
    [code.py]
2024-03-01 wavesynth filter env works more like it should now
2024-03-02 wavesynth: patch save/load sorta works, added patch name to display, reworked wave_select logic, added noise wave_select
    [code.py]
2024-03-04 wavesynth: add basic velocity sensitivity
2024-07-04 finally getting some arduino examples
2024-07-06 working on arduino gui
2025-02-15 route +5V to PCM5102 module instead of +3V3, fixes #2
    [pico_test_synth1.brd, pico_test_synth1.sch]
2025-04-15 redraw board in kicad, add ability for using pico2 rp2350
    [pico_test_synth2.kicad_pcb, pico_test_synth2.kicad_sch]
2025-04-18 pcb2 cleanup before production
    [pico_test_synth2.kicad_pcb, pico_test_synth2.kicad_sch]
2025-04-18 move pico_test_synth1 sch
    [pico_test_synth1.brd, pico_test_synth1.sch]
2025-04-28 update hwtest for modern circuitpython
2025-05-03 fix up hwtest/code.py a little
    [code.py]
2025-05-05 pico_test_synth2 updates
    [pico_test_synth2.kicad_pcb, pico_test_synth2.kicad_sch]
2025-05-15 add pico_test_synth2 to readme
    [pico_test_synth2.kicad_sch]
2025-05-27 tbish: misc fixes, added delay (but off)
    [code.py, tbish_synth.py]
2025-05-29 hooked up delay to knobs, added first cut at save/load of ParamSets
2025-05-31 tbish: wired up accent param better, tweaked distortion, added saw2 wave
2025-06-05 pico_test_synth2 5Jun2025 production run
    [pico_test_synth2.kicad_pcb, pico_test_synth2.kicad_sch]
2025-06-09 fix spdx on .py
    [code.py, pitch_glider.py, synth_setup_pts.py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]
2025-11-28 update hwtest/code.py to work with pico_test_synth2 board
2025-12-02 fix synth1 for cirpy 10 and pico_test_synth2
    [code.py]
2025-12-02 add filter type selection to synth1
2025-12-04 synth1: add simple filter envelope
2025-12-05 synth1 now has per-note filter env with adjustable filter env time using exp filter instead of linear
2025-12-08 change synth_tools/instrument to change filter type on keypress
2026-08-05 update circuitpython requirements.txt
2026-09-06 first cut at updates
2026-09-07 fix up polysynth and swarm a little
    [code.py]
2026-09-08 rework synthtools_polysynth demo to have a categorized menu
    [code.py]
2026-11-11 synthtools_polysynth: add MIDI LED status
